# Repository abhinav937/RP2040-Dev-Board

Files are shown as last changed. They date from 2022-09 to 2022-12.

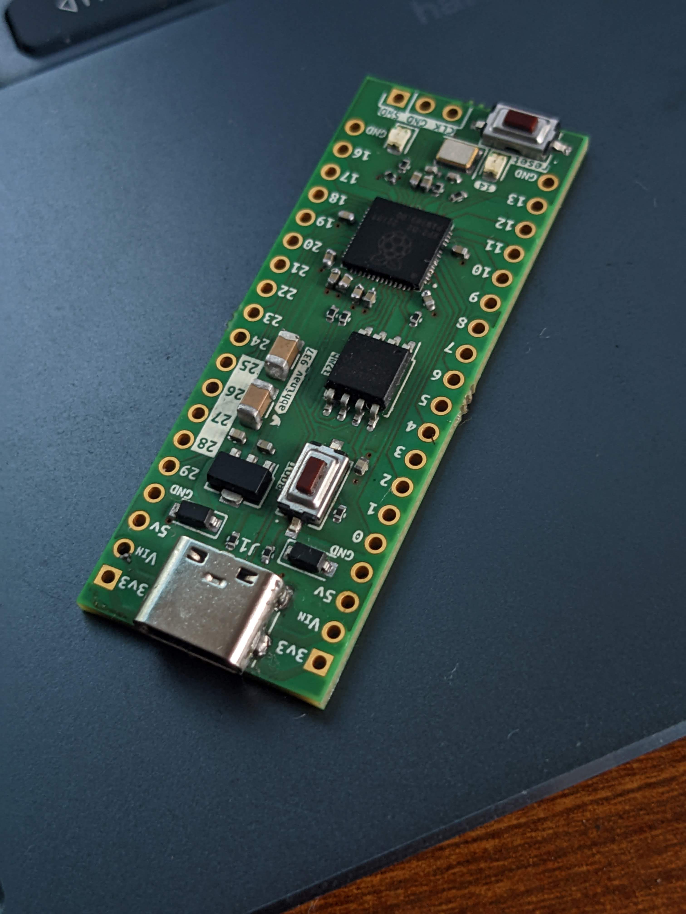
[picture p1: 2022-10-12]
Photos/PCBA/PXL_20220930_090836477.NIGHT.jpg

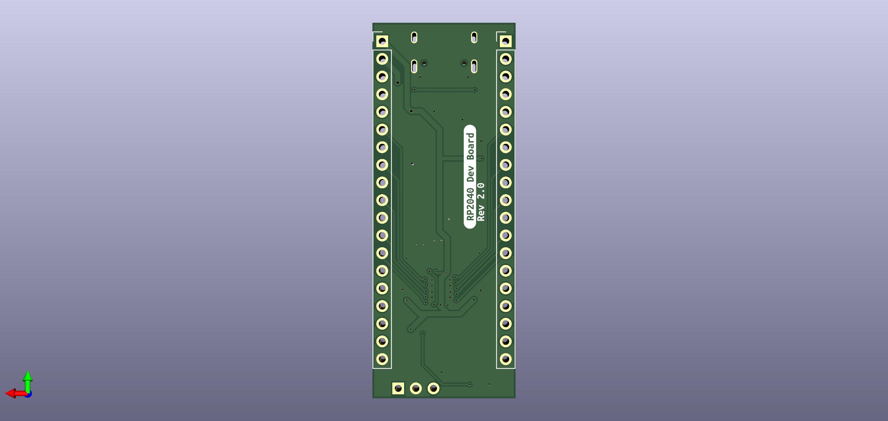
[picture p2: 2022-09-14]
Photos/Renders/pic_5.jpg

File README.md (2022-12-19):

# RP2040-Dev-Board
PCB Design(4 Layer) of Breadboard friendly RP2040 Dev Board with USB-C. <br /> 

#### Layer:

Layer 1: Front Cu <br /> 
Layer 2: Gnd <br /> 
Layer 3: Gnd <br /> 
Layer 4: Back Cu <br /> 

Initially my designs had inner layers as gnd and 3.3V, I got some netlist parity when I uploaded to my PCB manufacturer. But KiCad wasn't showing any errors in DRC, So I made both layers as Gnd.
#### Manufacturing
All components were purchased in [lcsc.com](lcsc.com) except RP2040, Which I purchased locally for 80Rs(~$1)/μC from robu.in. <br /> 

LCSC BOM: https://github.com/abhinav937/RP2040-Dev-Board/blob/main/RP2040_LCSC_BOM.csv <br /> 

I got my PCBs manufactured from [Aisler](aisler.net). <br /> 

Rev2 has lot of inspiration from michael rangen's PCB layout. Also I've used KiBuzzard for silkscreen texts, Which I personally like very much.
#### Refer my [documentation](https://github.com/abhinav937/RP2040-Dev-Board/blob/main/RP2040%20Dev%20Board%20Documentation_v01.pdf) for full information.

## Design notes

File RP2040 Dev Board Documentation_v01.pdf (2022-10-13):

# RP2040 Development Board

30 September 2022

Abhinav Chinnusamy

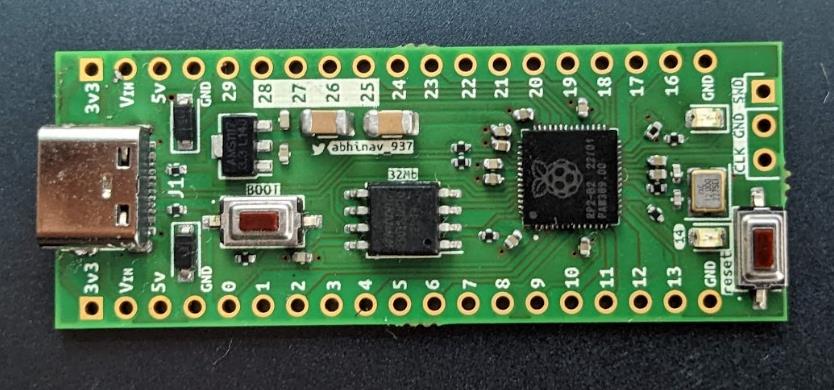
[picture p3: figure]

Figure 1. Top View of
assembled PCB

### Introduction

The RP2040 Development Board is a small, low-cost, versatile board. It has an RP2040 microcontroller, an onboard LED, a USB-C connector, and an SWD interface. The USB bootloader allows it to be flashed without any adapter in a drag-and-drop manner. It is also possible to flash and debug with its SWD interface using an external adapter.

### Hardware

- Dual-core Arm Cortex-M0+ processor running up to 133MHz
- 264KB on-chip SRAM
- 32MB onboard QSPI flash with XIP capabilities
- 26 GPIO pins
- 3 Analog inputs
- 2 UART peripherals
- 2 SPI controllers
- 2 I2C controllers
- 16 PWM channels
- USB 1.1 controller (host/device)
- 8 Programmable I/O (PIO) for custom peripherals
- On-board LED

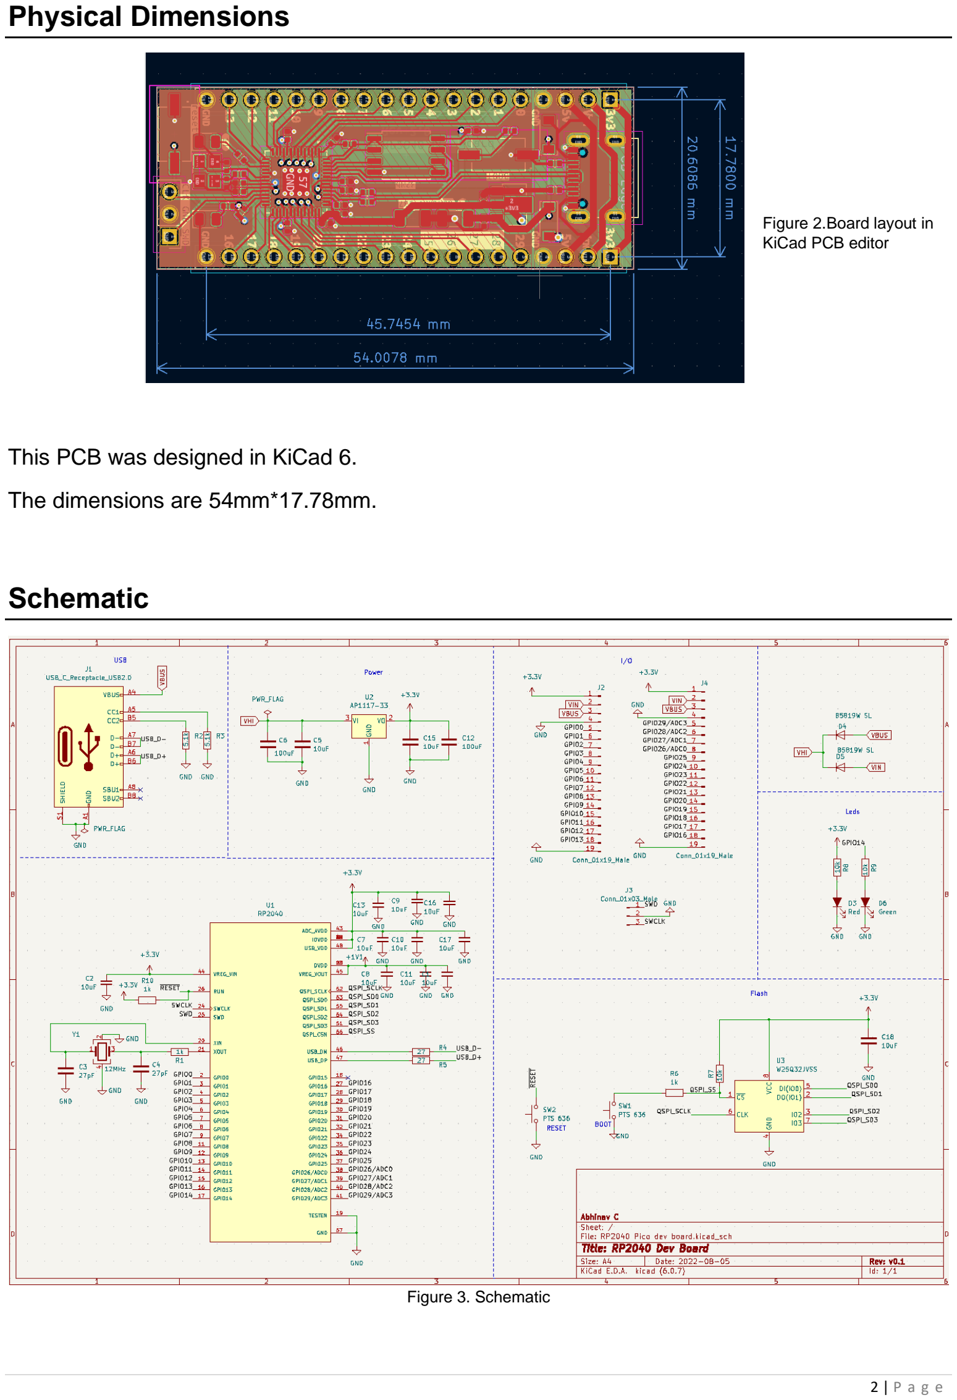
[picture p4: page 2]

2 | P a g e

### Physical Dimensions

Figure 2.Board layout in
KiCad PCB editor

This PCB was designed in KiCad 6.

The dimensions are 54mm*17.78mm.

### Schematic

Figure 3. Schematic

### Input supply

Figure 4. Power
and USB Section

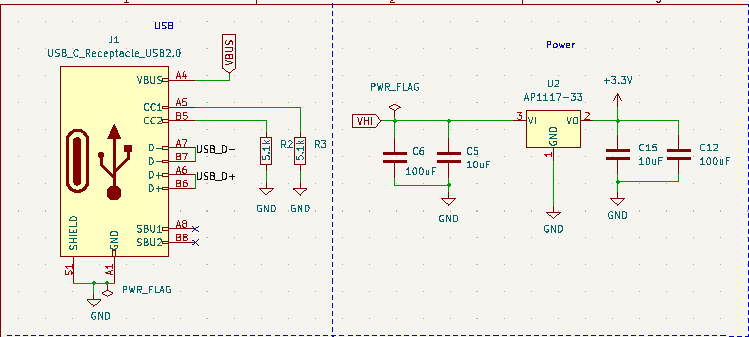
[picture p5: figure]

The input power connection for this Design is via the 5V VBUS of USB-C, as the CC pins are pulled down with 5.1k resistors. Also, it can be powered with the Vin pin up to 18V max and a min of 5V.

The Data lines in the USB-C port are connected to RP2040 directly, as it has native USB functionality.

We need only 3.3V for RP2040, so AMS1117 is chosen to deliver 3.3V up to 1A max.

It is advised to choose 0805 capacitors instead of smaller 0603 or 0402 because of DC Biasing.

Bigger the footprint, the lesser the DC Biasing (in MLCC, it also depends on brands). If the size is a constraint, more decoupling capacitors should be used.

### Crystal Oscillator

Figure 5. Oscillator

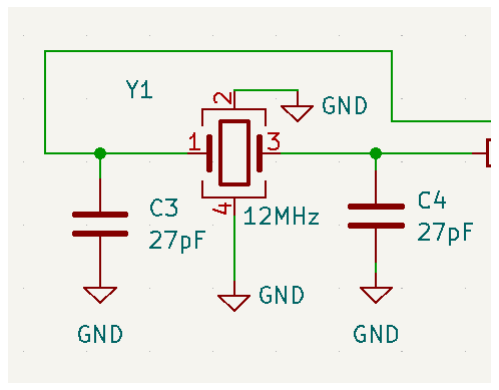
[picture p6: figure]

Do not forget to add load capacitance to the crystal. Otherwise, it might not oscillate.

Please choose the crystal's suitable capacitors to match its load capacitance. It's not a common value to use.

Refer to datasheets and calculate the C3 and C4(figure 5) for better results.

There are methods online to calculate it.

### How many decoupling capacitors are to be used?

Figure 6. A section of the schematic showing the RP2040 power supply inputs, voltage regulator, and decoupling capacitors

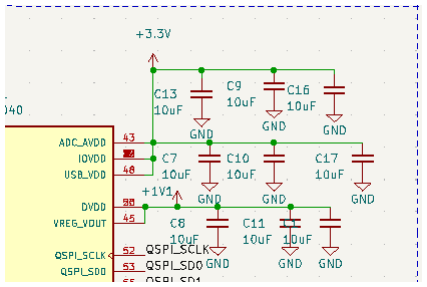
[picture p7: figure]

For the power input of RP2040, we require some decoupling capacitors for filtering purposes.

Raspberry Pi suggests using at least seven 100nF 0402 MLCC caps on 3.3V Power and two 100nF, 1uF 0402 MLCCs on 1.1V power pins.

If more oversized (>0402) caps are used, fewer capacitors can be placed because of lower DC bias in larger footprint caps.

These capacitors should be placed very close to the Microcontroller as possible, as it prevents the voltage level in the immediate vicinity from dropping too much when the current demand suddenly increases.

### LEDs

Figure 7. A section of the schematic showing the Onboard led and Power led.

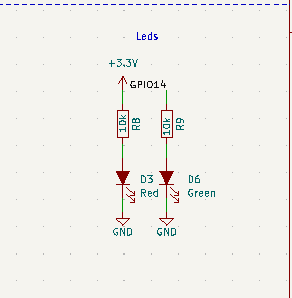
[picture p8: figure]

There are two LEDs on the PCB.

One (Red) is connected to the 3V power track.

Other LED(Green) connected to GPIO pin 14 for Onboard LED.

## PCB Design

The PCB was designed in KiCad v6 with 4 layers, the middle layers being gnd and the outer layers being mixed signal and Power.

### Physical Stackup

Figure 8.
Stack-up
specifications
of the Board.

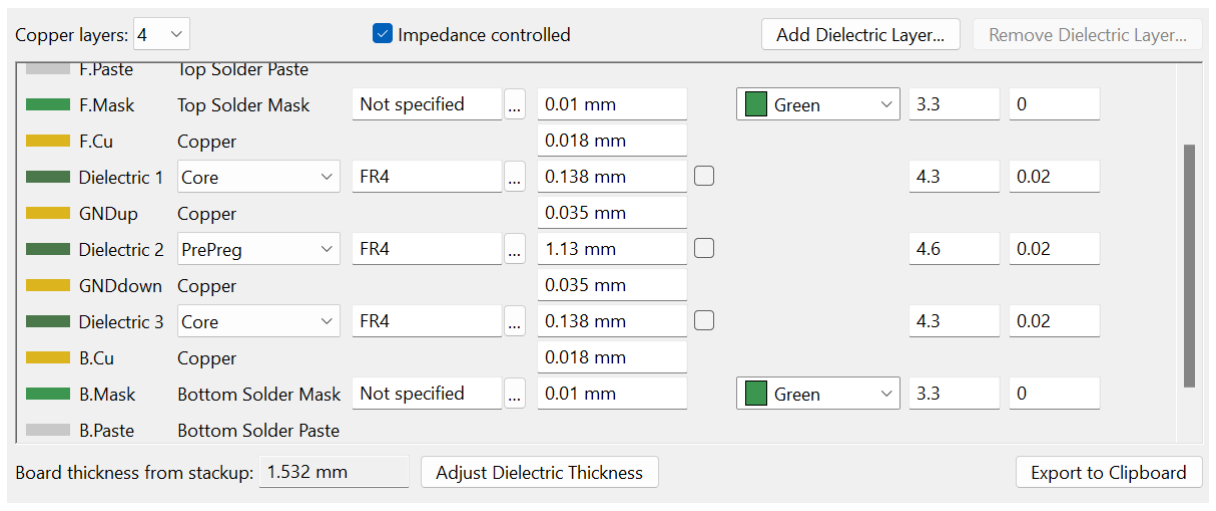
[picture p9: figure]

The above figure shows the stack-up specifications of the Board. This depends on the manufacturing capability of the PCB Manufacturer. I used the specs listed by AISLER for 4-layer Board.

### Tracks and Vias

Figure 9. Pre-defined Track and Via dimensions.

I've used 3 different widths for tracks—the lesser width track(0.2mm) for connecting microcontroller pins to other components. And the broader track for Power.

Track width depends on the current it can handle under a specific temperature rise. KiCad has an inbuilt tool to calculate it.

One way to have narrow tracks is to increase the thickness of the copper layer. I used 1oz of copper thickness.

Increasing the thickness increases the manufacturing cost of PCBs.

### Vias in uC's Copper Pad

Figure 10. A section of the PCB Design showing vias placed in RP2040 footprint.

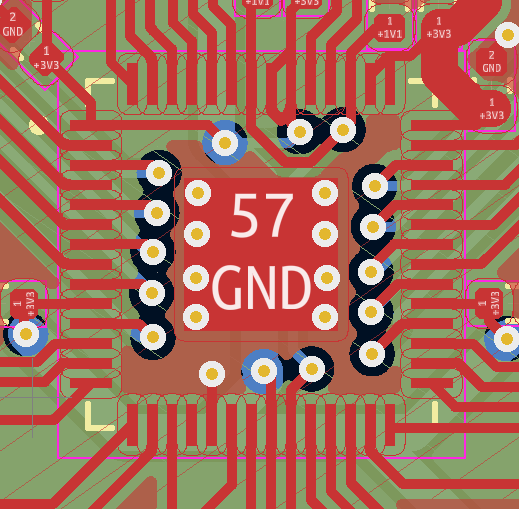
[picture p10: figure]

The unconnected vias on copper pads were placed for heat dissipation for the Microcontroller.

### Copper fills

Figure 11. A section of the PCB Design showing the copper fill zone (highlighted).

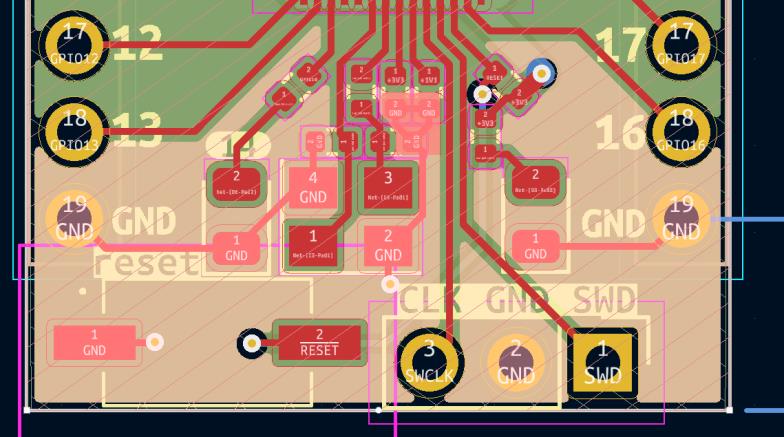
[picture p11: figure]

Copper fill zones are placed in PCBs to increase EMI performance and heat dissipation, and signals can take the shortest path.

In this Design, I've placed copper fills in both inner layers, which are grounded. And there are a few copper fills on the top and bottom for Power and Gnd.

### Breadboard Friendly?

Figure 12. A section of the PCB Design showing distance between header pins pads.

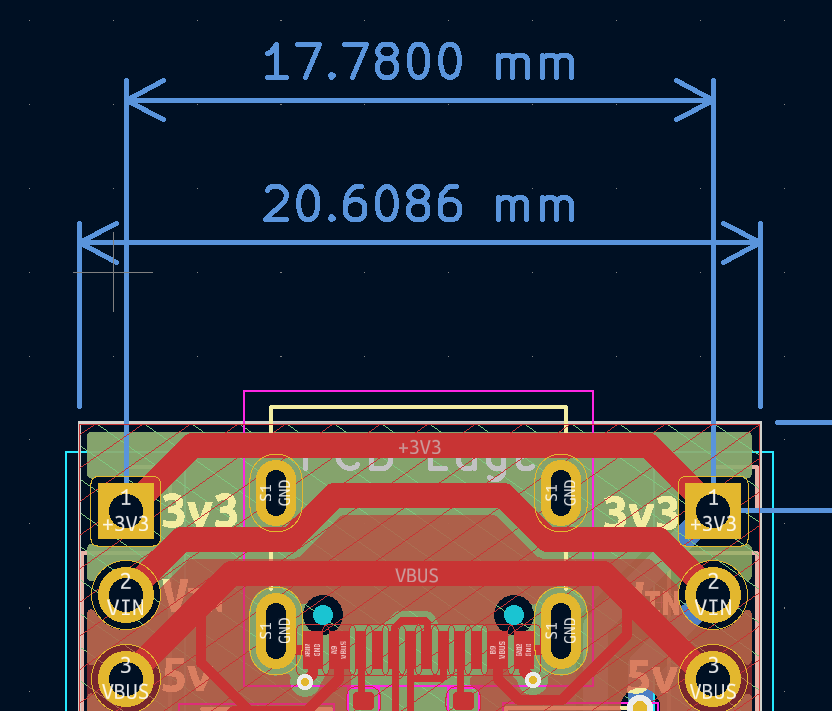
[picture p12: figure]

This Board was made with consideration to be breadboard friendly. So, the header pins are separated at 17.78mm, like Arduino Nano.

### Silkscreen Text

Figure 13. KiBuzzard tool for silkscreen text.

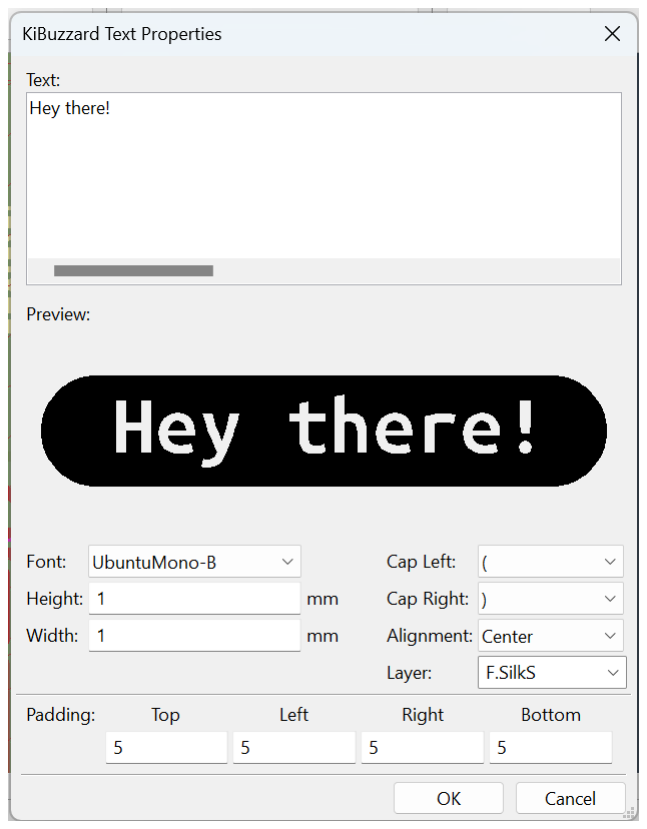
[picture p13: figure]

KiBuzzard is a KiCad Plugin for creating labels in various fonts and inverted backgrounds developed by gregdavill. (https://github.com/gregdavill/KiBuzzard)

This plugin allows the creation of boxed texts in various formats in silkscreen. I recommend this plugin very much.

### PCB Manufacturing

To manufacture the designed PCB, export the Gerber and drill files and upload them to the PCB manufacturer's website.

Or there are plugins for top-rated PCB manufacturers like AISLER, PCBWay, JLCPCB, et Cetra.

After installing the plugin, A single click to upload required files directly to their website.

Figure 14. AISLER push plugin in KiCad.

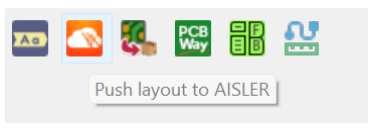
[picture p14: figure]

It's preferred to order a stencil with the PCBs if assembly service is not chosen. There are 0402 components, and the Microcontroller lead pitch (pin to pin) is 0.4mm.

Personal preference:

I prefer AISLER for manufacturing the PCBs. There are no delivery charges for basic delivery service; they were delivered to India within 7 days after the order was dispatched, and no customs duties were levied.

### Manufactured PCB from AISLER

Figure 15.
Manufactured
PCB.

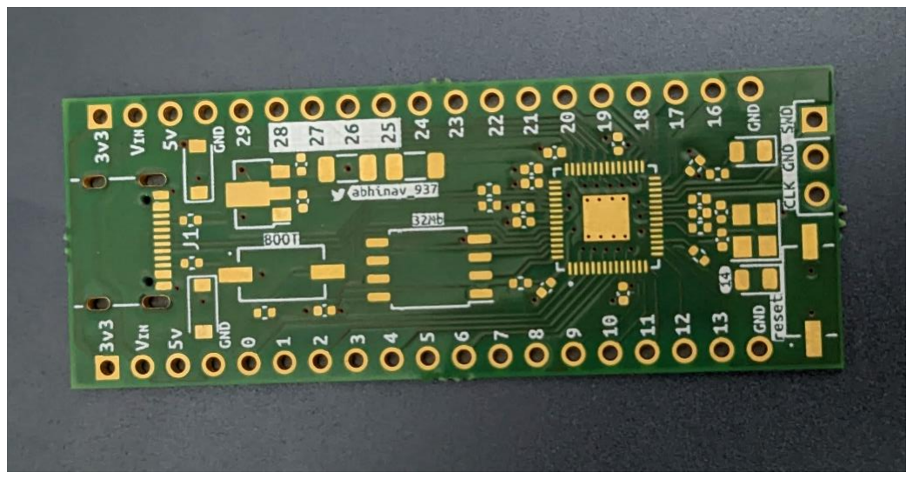
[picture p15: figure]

### Component sourcing

I sourced all components from lcsc.com except RP2040. RP2040 was purchased from robu.in.

There were no custom duties levied on components. But it took around 15 days for delivery—longer queue times in customs clearance.

Purchase more components than what you require for assembly.

I lost many SMD components while placing them on Board.

### Assembly

After sourcing all components and PCBs, tools like a Reflow oven or Hot Plate, Solder paste, Flux, and soldering iron are required.

I reflowed the components with a Reflow Oven (Model: T962A).

Figure 16. T962A Reflow oven

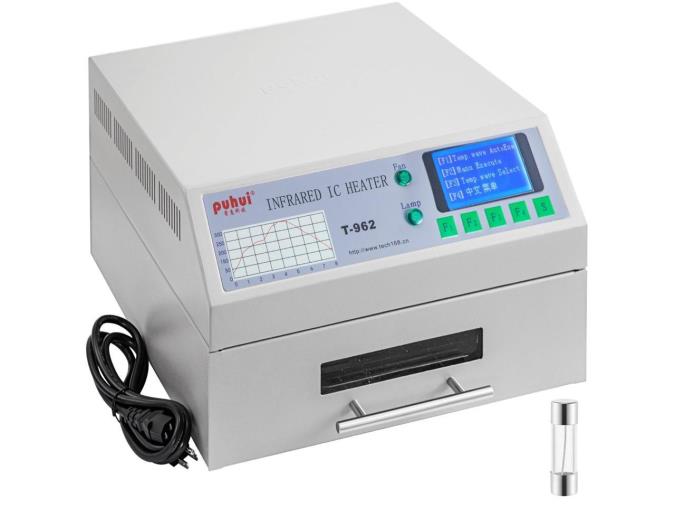
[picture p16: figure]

Assembly process:

1. Solder Paste deposition
2. Parts placement
3. Reflowing the PCB
4. Rework on bridged pads

### Solder Paste deposition

To apply solder paste on the pads, Secure the PCBs on a flat surface with pre-cut holders. If you don't have one, you may use some trash PCBs of the same thickness to hold it.

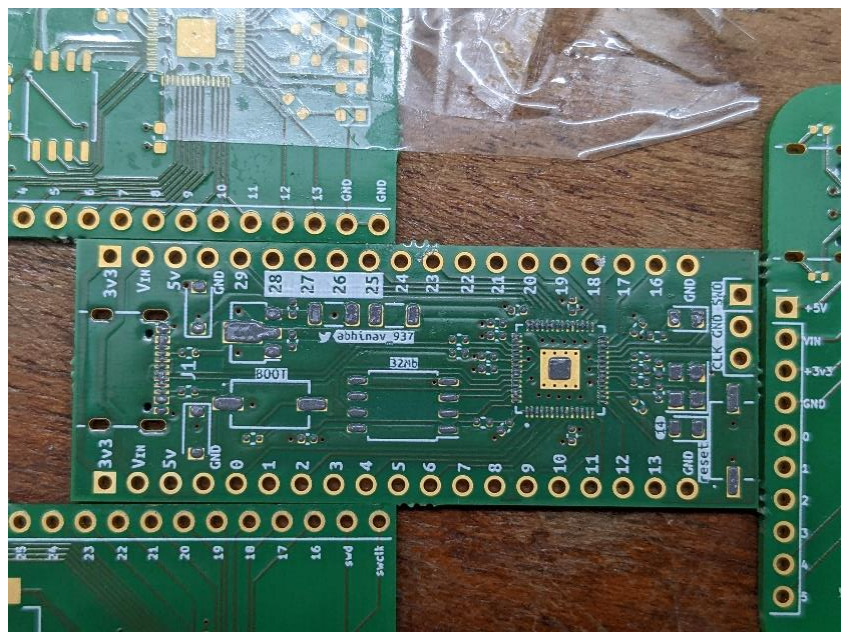
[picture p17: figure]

Figure 17. Securing the
PCB with trash PCBs on a
flat surface.

Then align the stencil on the top of the PCB, ensure it's properly aligned, and secure it for best results.

Figure 18. Aligning the
PCB and securing it.

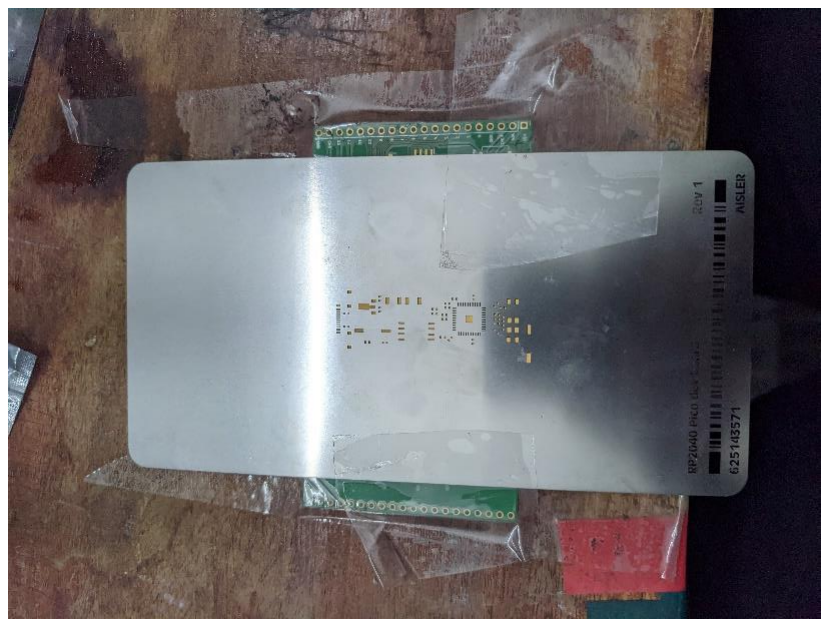
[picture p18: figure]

Prepare the solder paste by mixing it properly. Make sure to check that it's not expired.

Refrigerated solder paste gives the best results.

Take some amount(excess) solder paste and place it on one side of the stencil.

Using a squeegee or an old credit card, slide the solder paste on the stencil at an angle of 60˚.

Then gently remove the stencil.

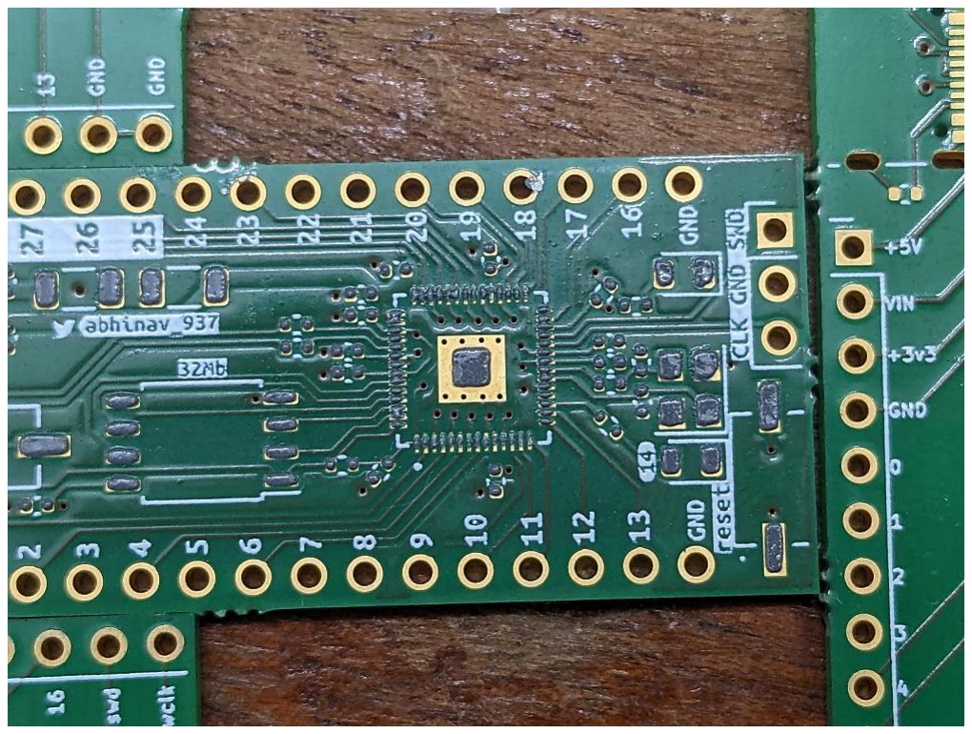
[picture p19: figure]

Figure 19. Solder
paste applied
PCB.

### Parts placement

Before placing the parts, have a copy of BOM to mark the components placed and sourced to avoid confusion during placement.

I prefer iBOM, a KiCad plugin, and a convenient BOM listing that can correlate visually and easily search for components and their placements on the PCB.

Figure
20.
iBOM
tool.

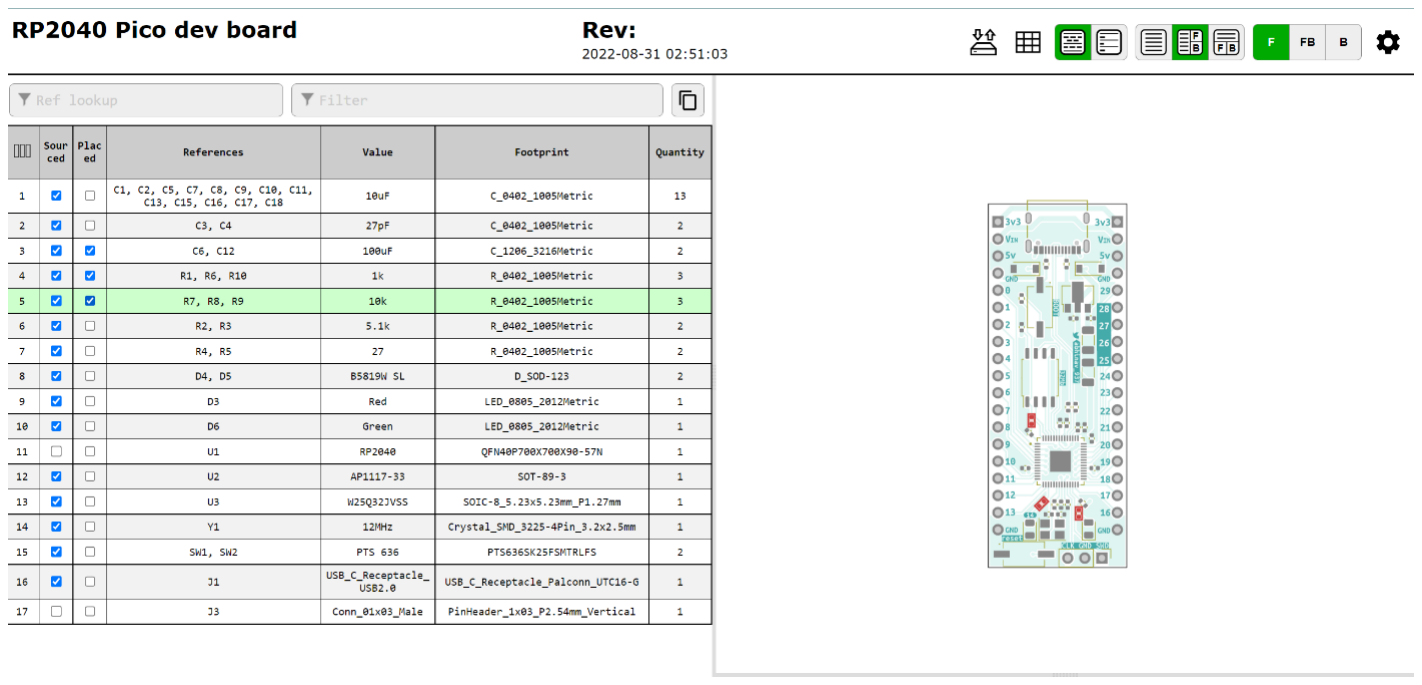
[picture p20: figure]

To place the SMD components, use a bent-tip tweezer to pick and place it on PCB and give a gentle push from the top.

Try to place the components properly on the first try. Re-positioning may push the solder paste and disturb it.

Do not place THT components for reflow. It can be hand soldered later.

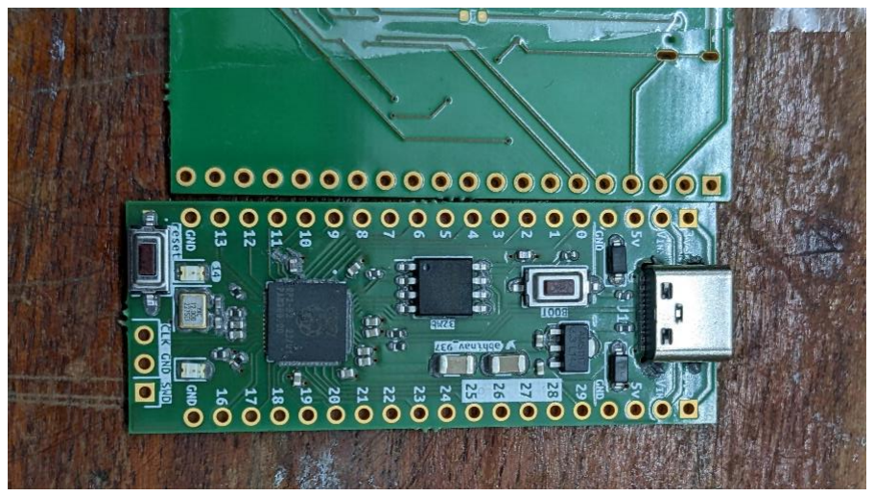
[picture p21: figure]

Figure 21. PCB after
placing the
components and ready
for reflowing.

### Reflowing the PCB

The first step in reflowing is to set the temperature profile in the reflow oven.

T962A reflow oven has 8 different temperature profiles. You can choose one after referring to your solder paste datasheet and components datasheets.

I used a custom profile which gave a better result for the XG-50 solder paste.

Figure 22. Custom
reflow profile on T962A
Oven.

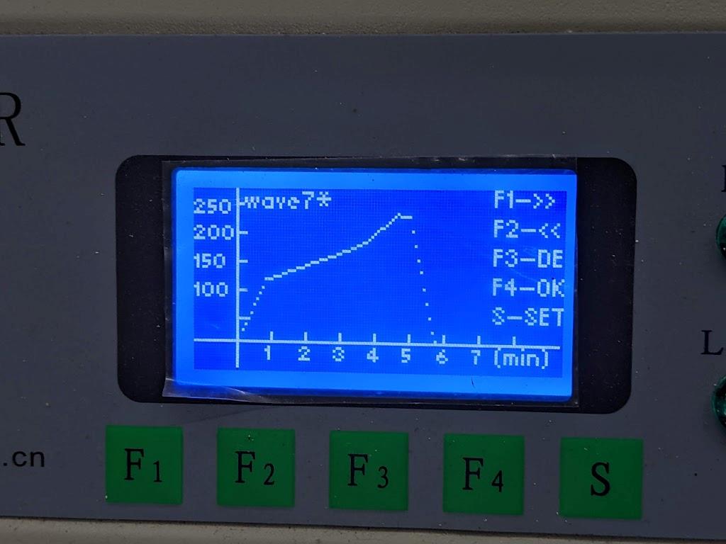
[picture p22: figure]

Now, gently place the PCB in the Oven and start the reflow oven.

Using this Oven in a ventilated room or with a venting system to extract the fumes is good practice.

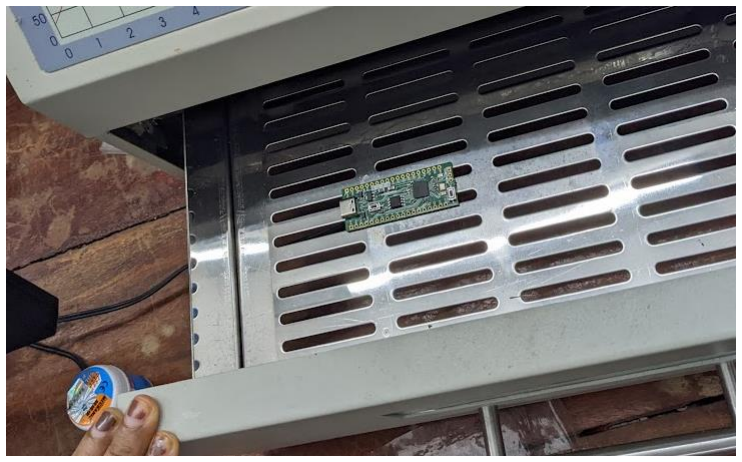
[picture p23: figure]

Figure 23.
Semi-assembled
PCB placed
in Oven for
reflowing.

It takes 5 minutes and 20 seconds to complete the reflow for this solder profile. When the Oven starts beeping, please turn it off and wait some time for cooldown as the inside temperature could be more than 100˚.

Please do not take the Board right after the reflow process ends; the components are loose in hot solder.

After the Board cools down, take it out and check for solder bridges and short circuits.

### Rework on the bridged pads

It's not always that we get a perfect reflow.

Due to excess solder paste on some pads, the neighbouring pads get bridged.

The uC in my PCB got bridged pins.

So, we can rework it using one of the following methods.

### 1. Hot air rework station

We can reflow the component using the hot air station and scrap the excess solder.

Use Kapton tape to cover the other components while reworking on the uC.

Figure 24. Assembled
PCB Kapton taped for
rework on the uC.

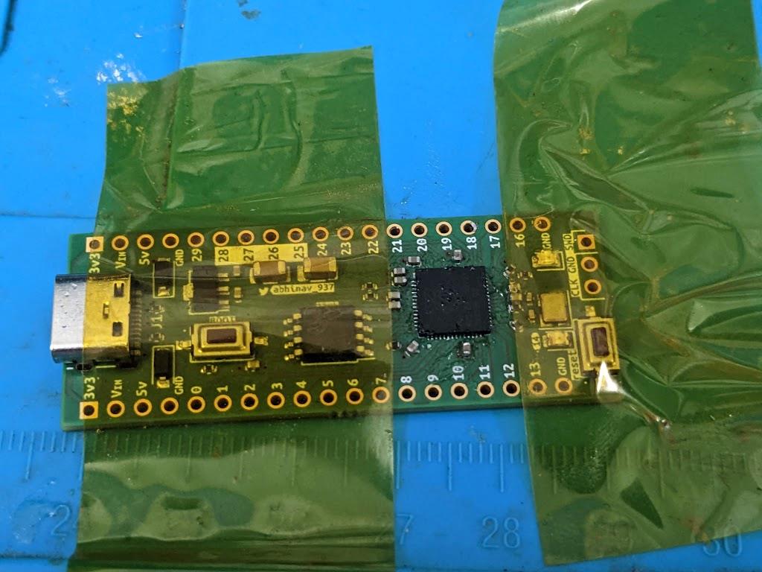
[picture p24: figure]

This method was not successful for me in getting rid of bridged pads.

### 2. Using a soldering iron

My idea was to try using a sharp tip soldering iron to remove the bridges, but I was unsuccessful.

Next, I tried using a properly tinned, angled flat tip soldering iron and successfully removed the bridges.

But still, there were shorts in the Power and GPIO pins of uC.

Finally, I came to know that uC was bridged from the inside due to excess solder paste on the pads.

So, I tried another method to resolve it.

### 3. Reflowing once again in Oven

I removed the uC from the PCB using the Hot air station and cleaned the pads and added some solder to it.

Then I applied some flux to the PCB, placed the uC, and reflowed in Oven.

Now there are no bridged pads, and connectivity is fine.

Still, the pads and vertical side of uC were not soldered properly. So, I reworked it with a soldering iron.

NOTE:

Use an ample amount of Flux while doing any rework.

Reflowing the PCBA multiple times can change the properties of the components.

E.g., Reflowing the crystal oscillator more than once can change its frequency.

After resolving all the issues and checking the connectivity of pads and power tracks, we can solder the THT components and Power up the Board.

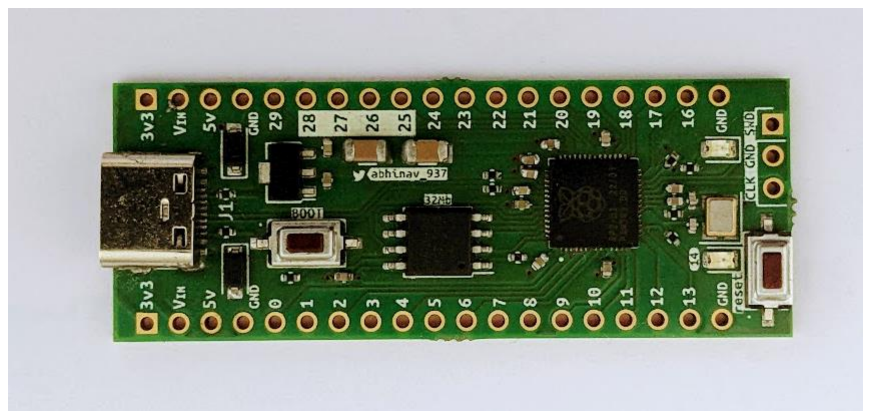
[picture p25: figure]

Figure 25. Fully
assembled working PCB
of RP2040 dev board.

### Testing

Ensure the Board has no shorts, and connect a USB-C cable from a charging brick or a computer.

If the Onboard Power led lights up, then Board is working fine (At least in the power section).

Connect the Board to a computer while pressing the Boot button and release it when mass storage (RPI-RP2) is detected.

This ensures that Board is working with full functionality.

If mass storage is not detected, solder the Flash pins of uC to pads properly or check for bridging.

NOTE: No drivers are required for USB serial connection.

Once Everything is working correctly, we can drop the compiled .UF2 file on the mass storage, and it starts running the program.

RP2040 officially supports C/C++ and MicroPython.

For MicroPython, Thonny (https://thonny.org/) IDE allows you to code in MicroPython, compile, and run on the Board by selecting the proper interpreter and flashing a special firmware.

For C/C++, VS Code and a few extensions allow us to write and compile the program with debugging functionalities.

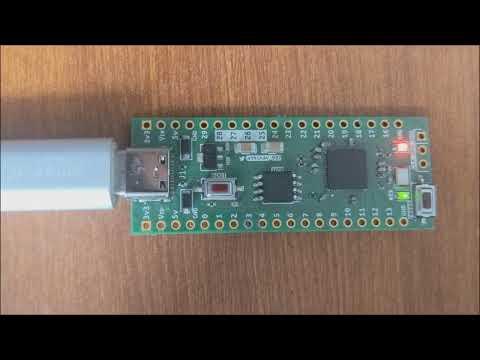
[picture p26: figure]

On-board Led Blink test

### References

https://datasheets.raspberrypi.com/rp2040/hardware-design-with-rp2040.pdf

https://twitter.com/sad_electronics

https://www.youtube.com/watch?v=kcwvuwetgEQ

https://www.digikey.in/en/maker/projects/hardware-design-with-the-rp2040-part-1-schematic/c4326f0fd813413698d617cf625125ee (https://www.digikey.in/en/maker/projects/hardware-design-with-the-rp2040-part-1-schematic/c4326f0fd813413698d617cf625125ee)

https://github.com/mrangen/RP2040-Dev-Board

https://github.com/gregdavill/KiBuzzard

https://www.kicad.org/

https://aisler.net/

https://lcsc.com/

https://www.puhuit.com/main/page_products_t962a_ir_ovenic_heater.html

https://thonny.org/

A Special thanks to sad_electronics (https://twitter.com/sad_electronics) and peg_iitdh (https://twitter.com/peg_iitdh) for their continuous support.

Design files: https://github.com/abhinav937/RP2040-Dev-Board

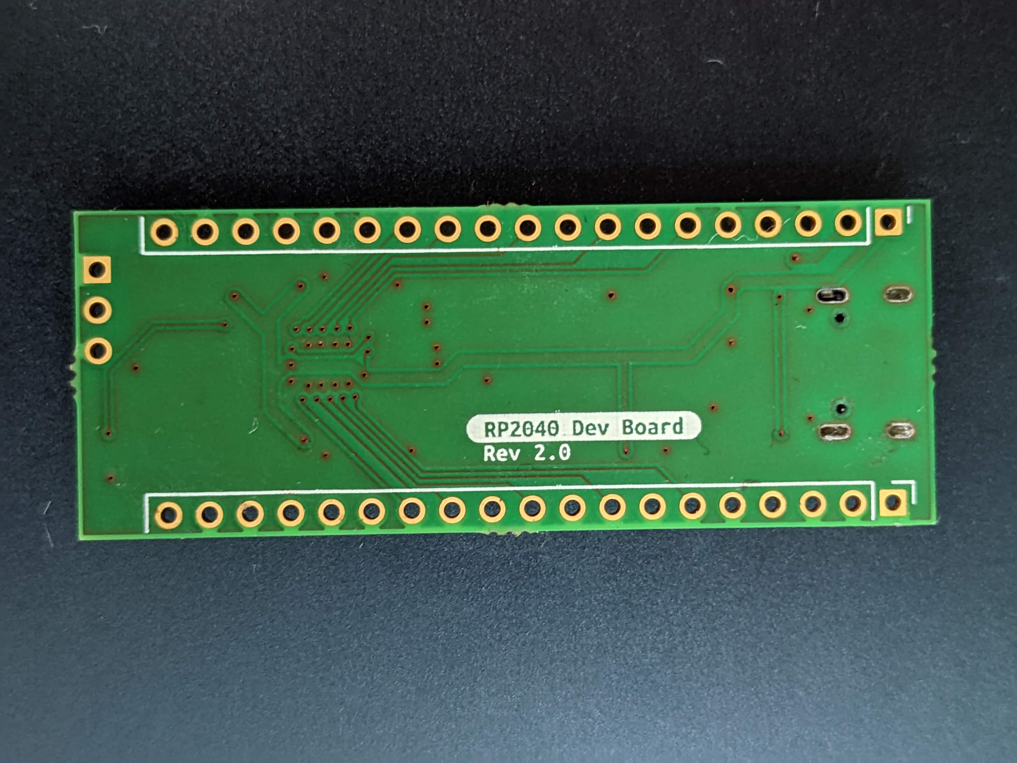
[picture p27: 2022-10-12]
Photos/PCBA/PXL_20220930_091015371.NIGHT.jpg

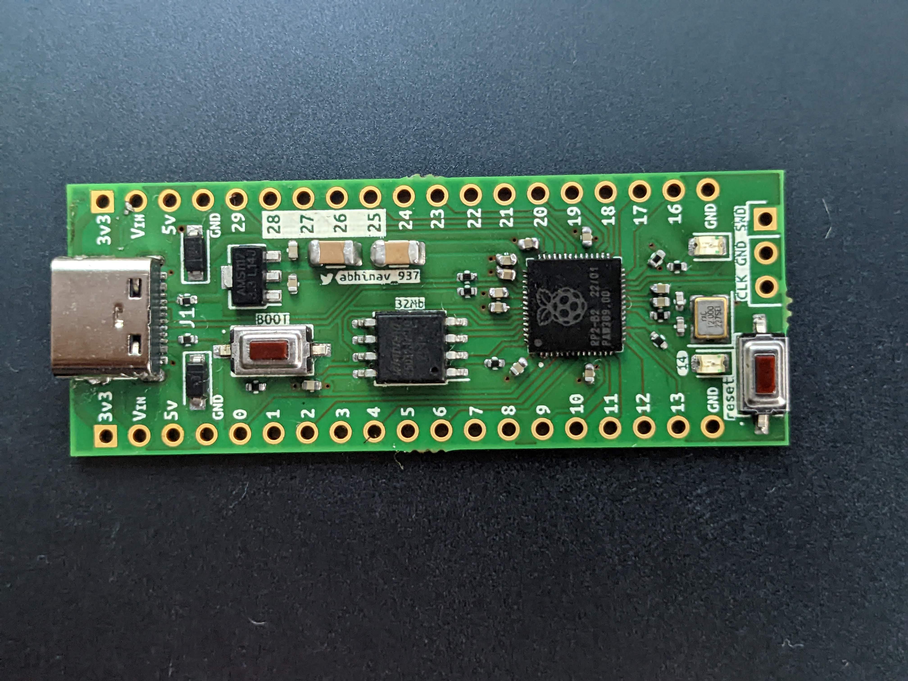
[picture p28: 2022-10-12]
Photos/PCBA/PXL_20220930_090942642.NIGHT.jpg

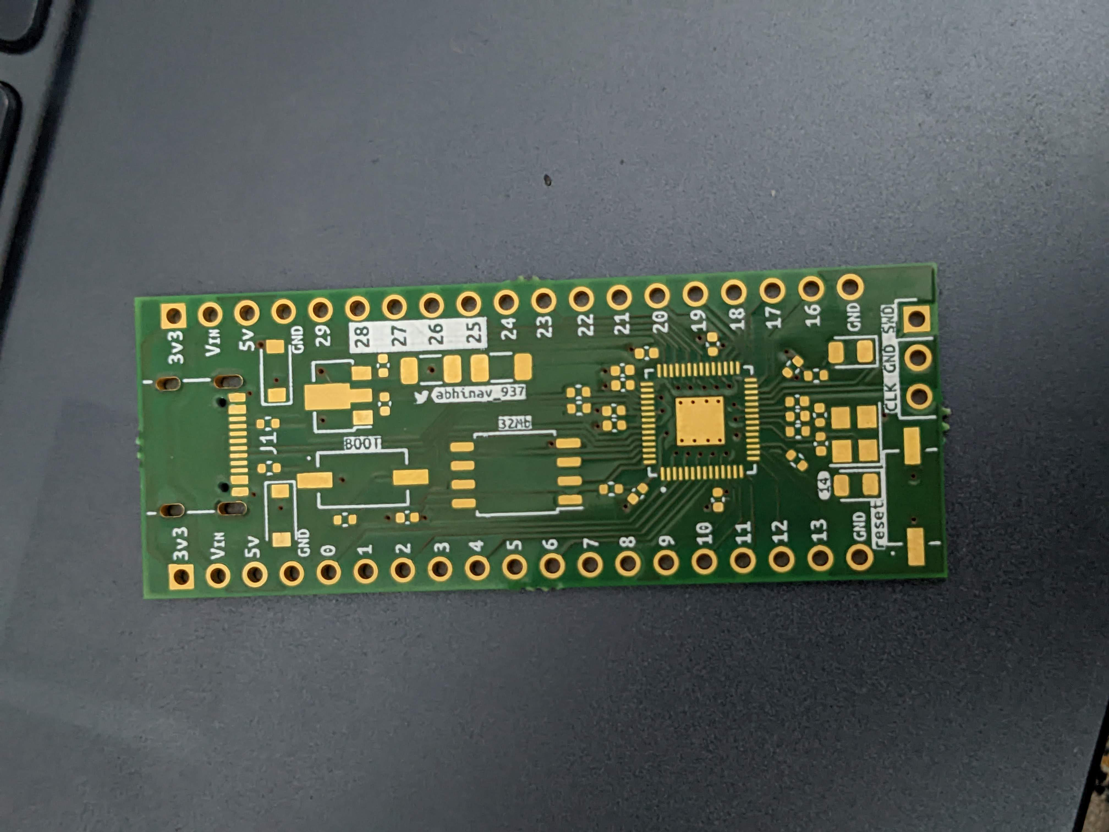
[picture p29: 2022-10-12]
Photos/PCBA/PXL_20220921_171338347.NIGHT.jpg

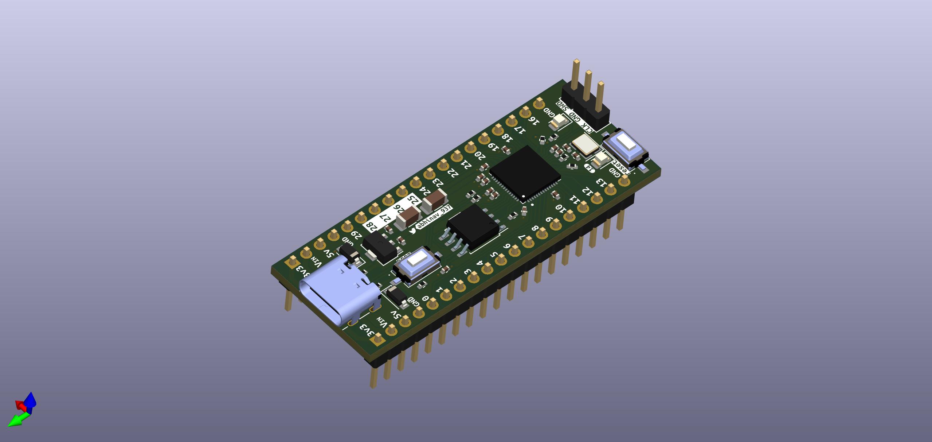
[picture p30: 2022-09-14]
Photos/Renders/pic_3.jpg

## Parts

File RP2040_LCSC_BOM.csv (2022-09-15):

LCSC Part Number | Manufacture Part Number | Manufacturer | Customer NO. | Package | Description | RoHS | Order Qty. | Min\Mult Order Qty. | Unit Price | Order Price
C8598 | B5819W SL | Jiangsu Changjing Electronics Technology Co., Ltd. |  | SOD-123 | 40V 600mV@1A 1A SOD-123 Schottky Barrier Diodes (SBD) ROHS | YES | 20 | 20\20 | $0.033900 | $0.68
C2689642 | PTS636SK25SMTRLFS | C&K |  | - | - Tactile Switches ROHS | YES | 12 | 1\1 | $0.097000 | $1.16
C15525 | CL05A106MQ5NUNC | Samsung Electro-Mechanics |  | 0402 | 6.3V 10uF X5R ±20% 0402 Multilayer Ceramic Capacitors MLCC - SMD/SMT ROHS | YES | 100 | 50\50 | $0.003300 | $0.33
C15008 | CL31A107MQHNNNE | Samsung Electro-Mechanics |  | 1206 | 6.3V 100uF X5R ±20% 1206 Multilayer Ceramic Capacitors MLCC - SMD/SMT ROHS | YES | 15 | 5\5 | $0.078400 | $1.18
C1570 | 0402CG300J500NT | FH (Guangdong Fenghua Advanced Tech) |  | 0402 | 50V 30pF C0G ±5% 0402 Multilayer Ceramic Capacitors MLCC - SMD/SMT ROHS | YES | 100 | 100\100 | $0.001100 | $0.11
C11702 | 0402WGF1001TCE | UNI-ROYAL(Uniroyal Elec) |  | 0402 | 62.5mW Thick Film Resistors 50V ±100ppm/℃ ±1% -55℃~+155℃ 1kΩ 0402 Chip Resistor - Surface Mount ROHS | YES | 100 | 100\100 | $0.000600 | $0.06
C25744 | 0402WGF1002TCE | UNI-ROYAL(Uniroyal Elec) |  | 0402 | 62.5mW Thick Film Resistors 50V ±100ppm/℃ ±1% -55℃~+155℃ 10kΩ 0402 Chip Resistor - Surface Mount ROHS | YES | 100 | 100\100 | $0.000700 | $0.07
C25905 | 0402WGF5101TCE | UNI-ROYAL(Uniroyal Elec) |  | 0402 | 62.5mW Thick Film Resistors 50V ±100ppm/℃ ±1% -55℃~+155℃ 5.1kΩ 0402 Chip Resistor - Surface Mount ROHS | YES | 100 | 100\100 | $0.000600 | $0.06
C84256 | NCD0805R1 | Foshan NationStar Optoelectronics |  | 0805 | Red 0805 Light Emitting Diodes (LED) ROHS | YES | 50 | 50\50 | $0.013000 | $0.65
C84257 | NCD0805C1 | Foshan NationStar Optoelectronics |  | 0805 | Green/Yellow-Green 0805 Light Emitting Diodes (LED) ROHS | YES | 50 | 50\50 | $0.016800 | $0.84
C165948 | TYPE-C-31-M-12 | Korean Hroparts Elec |  | SMD | 250mA 1 16 Female Type-C SMD USB Connectors ROHS | YES | 15 | 1\1 | $0.219300 | $3.29
C179173 | W25Q32JVSSIQ | Winbond Elec |  | SOIC-8 | SOIC-8 NOR FLASH ROHS | YES | 10 | 1\1 | $0.439300 | $4.39
C9002 | X322512MSB4SI | Yangxing Tech |  | SMD3225-4P | 12MHz SMD Crystal Resonator 20pF ±10ppm ±30ppm -40℃~+85℃ SMD3225-4P Crystals ROHS | YES | 10 | 5\5 | $0.090200 | $0.90
C5120796 | AMS1117-3.3V | MSKSEMI |  | SOT-89 | SOT-89 Linear Voltage Regulators (LDO) ROHS | YES | 20 | 10\10 | $0.074200 | $1.48
C25100 | 0402WGF270JTCE | UNI-ROYAL(Uniroyal Elec) |  | 0402 | 62.5mW Thick Film Resistors 50V ±100ppm/℃ ±1% -55℃~+155℃ 27Ω 0402 Chip Resistor - Surface Mount ROHS | YES | 100 | 100\100 | $0.000500 | $0.05

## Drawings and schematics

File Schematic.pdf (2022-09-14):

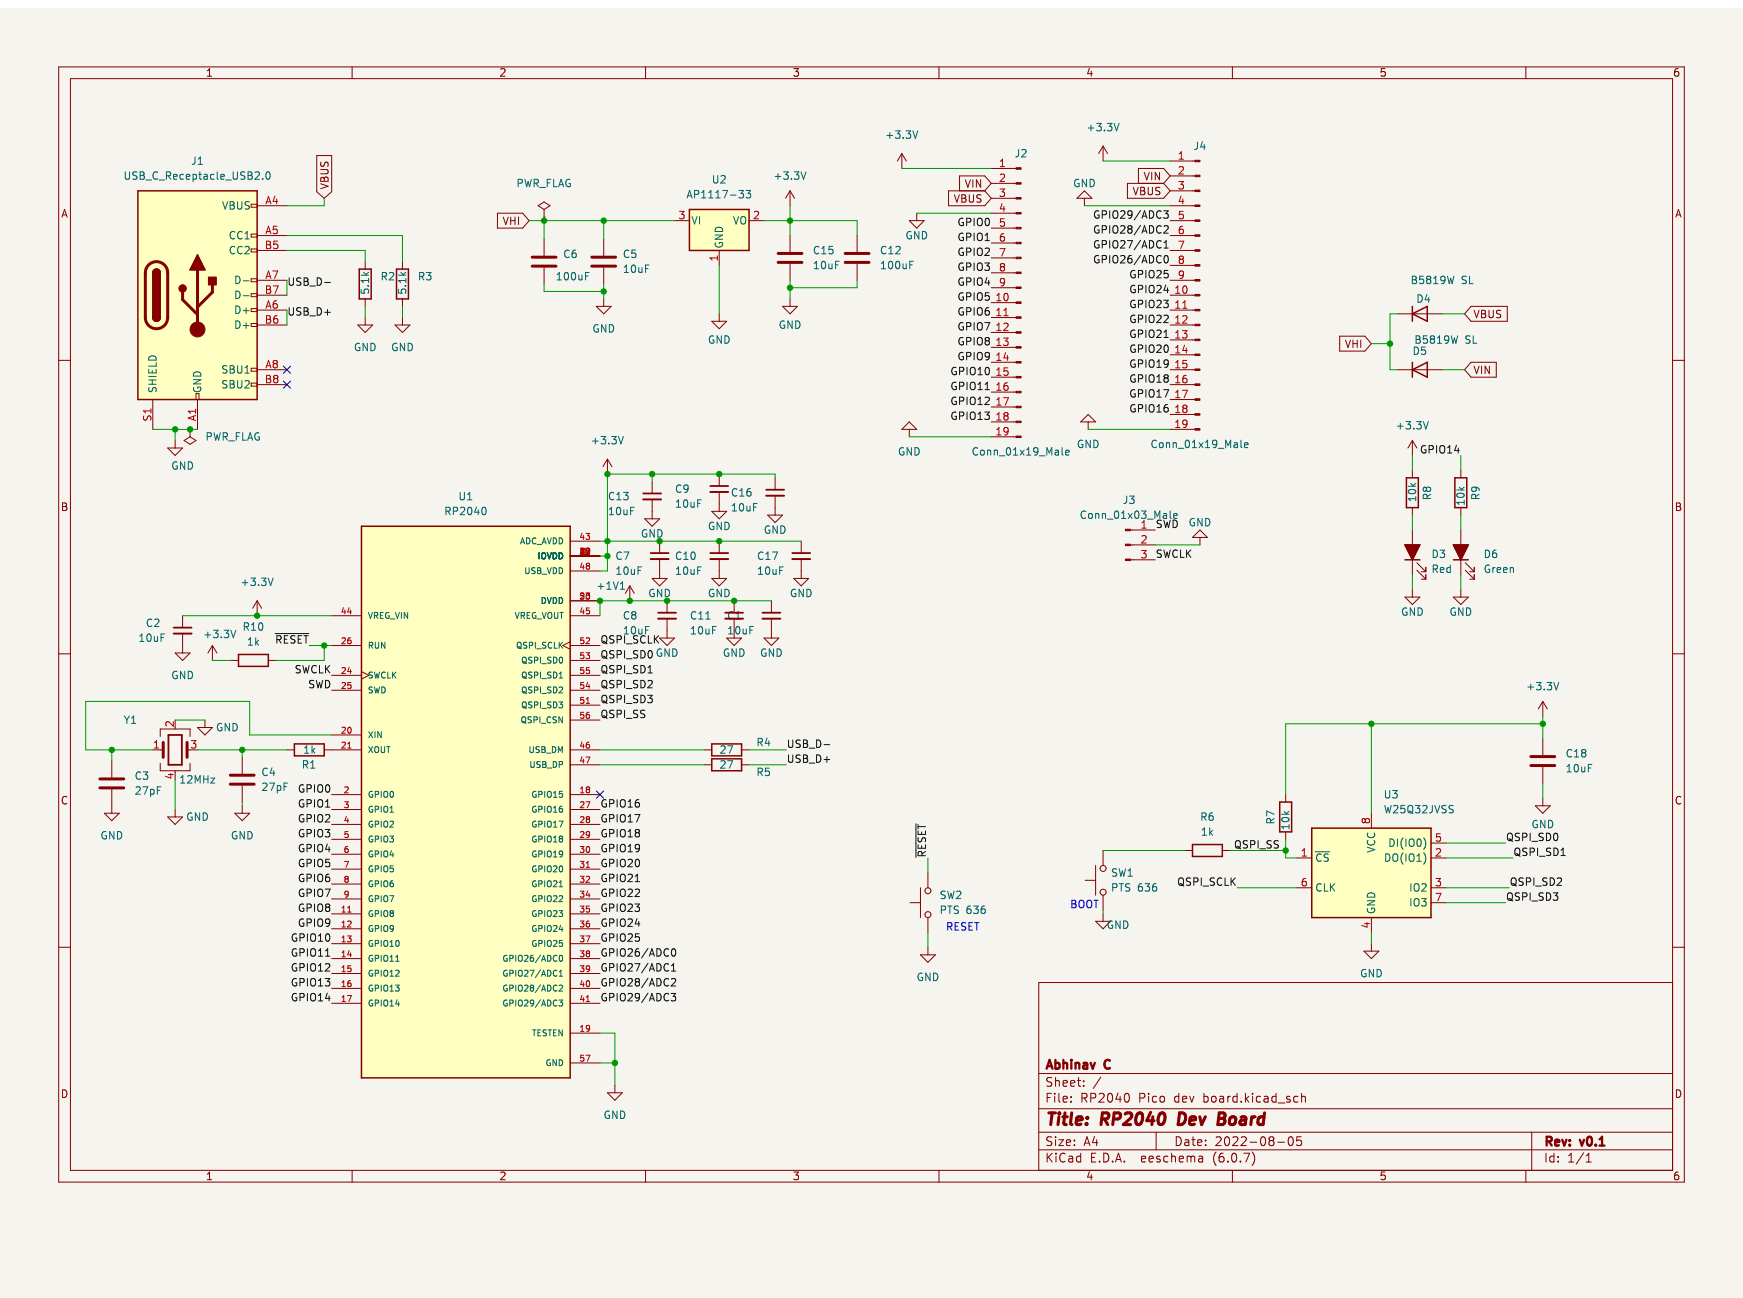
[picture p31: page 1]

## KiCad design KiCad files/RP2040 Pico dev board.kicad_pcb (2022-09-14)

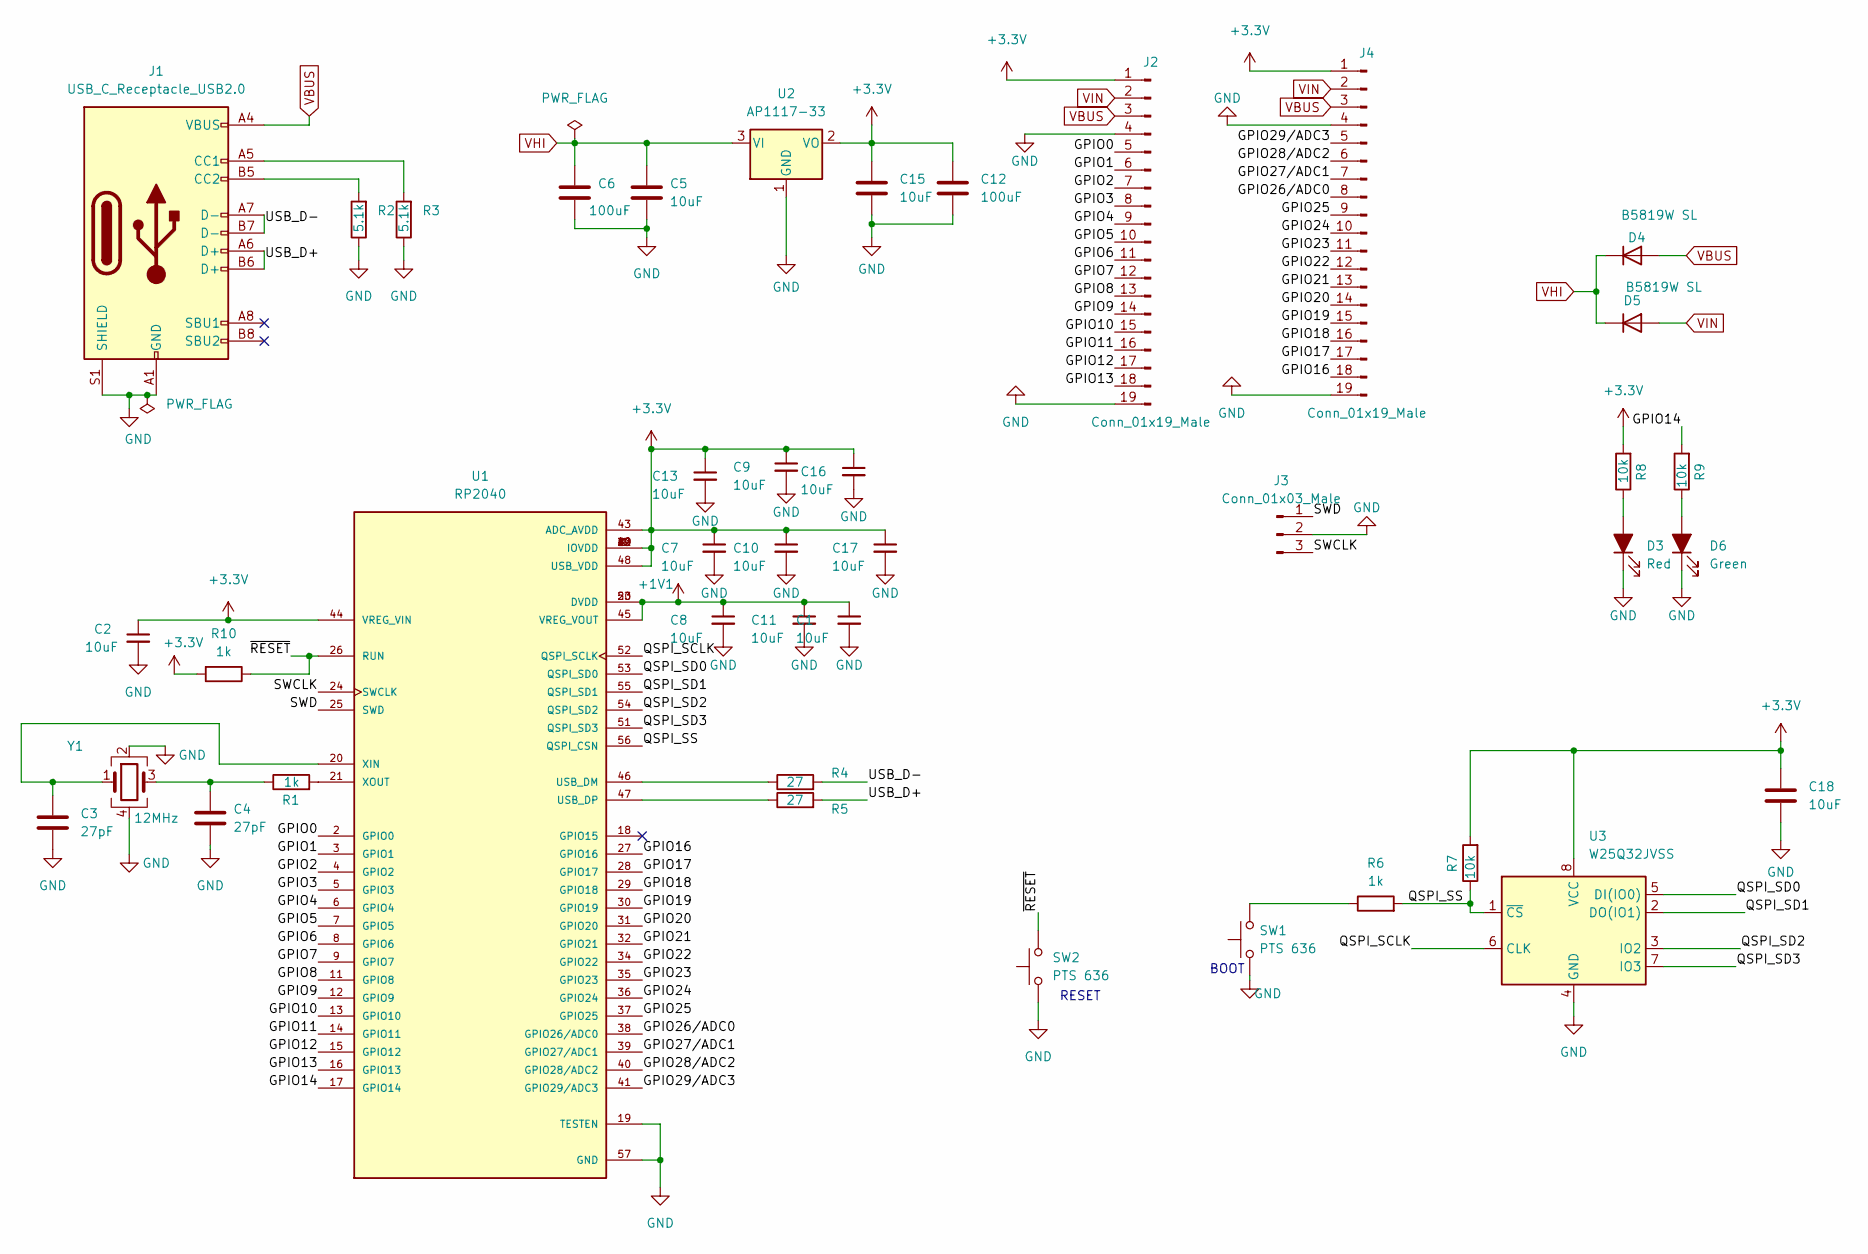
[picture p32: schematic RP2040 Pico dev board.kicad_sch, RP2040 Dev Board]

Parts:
C1, C2, C7, C8, C9, C10, C11, C13, C16, C17: 10uF; C_0402_1005Metric; JLCPCB P/N C15525
C3, C4: 27pF; C_0402_1005Metric
C5, C15, C18: 10uF; C_0402_1005Metric
C6, C12: 100uF; C_1206_3216Metric
D3: Red; LED_0805_2012Metric; JLCPCB P/N C2297
D4, D5: B5819W SL; D_SOD-123
D6: Green; LED_0805_2012Metric; JLCPCB P/N C2297
J1: USB_C_Receptacle_USB2.0; USB_C_Receptacle_Palconn_UTC16-G
J2, J4: Conn_01x19_Male; PinHeader_1x19_P2.54mm_Vertical
J3: Conn_01x03_Male; PinHeader_1x03_P2.54mm_Vertical
R1: 1k; R_0402_1005Metric; JLCPCB P/N C11702
R2, R3: 5.1k; R_0402_1005Metric
R4, R5: 27; R_0402_1005Metric; JLCPCB P/N C25100
R6, R10: 1k; R_0402_1005Metric
R7, R8, R9: 10k; R_0402_1005Metric; JLCPCB P/N C25744
SW1, SW2: PTS 636; PTS636SK25FSMTRLFS
U1: RP2040; QFN40P700X700X90-57N; PARTREV 1.6.1
U2: AP1117-33; SOT-89-3
U3: W25Q32JVSS; SOIC-8_5.23x5.23mm_P1.27mm
Y1: 12MHz; Crystal_SMD_3225-4Pin_3.2x2.5mm; JLCPCB P/N C9002

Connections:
+1V1: C1.1, C8.1, C11.1, U1.23 (DVDD), U1.45 (VREG_VOUT), U1.50 (DVDD)
+3V3: C2.1, C7.1, C9.1, C10.1, C12.1, C13.1, C15.1, C16.1, C17.1, C18.1, J2.1, J4.1, R7.2, R8.2, R10.2, U1.1 (IOVDD), U1.10 (IOVDD), U1.22 (IOVDD), U1.33 (IOVDD), U1.42 (IOVDD), U1.43 (ADC_AVDD), U1.44 (VREG_VIN), U1.48 (USB_VDD), U1.49 (IOVDD), U2.2 (VO), U3.8 (VCC)
/GPIO0: J2.5, U1.2 (GPIO0)
/GPIO1: J2.6, U1.3 (GPIO1)
/GPIO2: J2.7, U1.4 (GPIO2)
/GPIO3: J2.8, U1.5 (GPIO3)
/GPIO4: J2.9, U1.6 (GPIO4)
/GPIO5: J2.10, U1.7 (GPIO5)
/GPIO6: J2.11, U1.8 (GPIO6)
/GPIO7: J2.12, U1.9 (GPIO7)
/GPIO8: J2.13, U1.11 (GPIO8)
/GPIO9: J2.14, U1.12 (GPIO9)
/GPIO10: J2.15, U1.13 (GPIO10)
/GPIO11: J2.16, U1.14 (GPIO11)
/GPIO12: J2.17, U1.15 (GPIO12)
/GPIO13: J2.18, U1.16 (GPIO13)
/GPIO14: R9.2, U1.17 (GPIO14)
/GPIO16: J4.18, U1.27 (GPIO16)
/GPIO17: J4.17, U1.28 (GPIO17)
/GPIO18: J4.16, U1.29 (GPIO18)
/GPIO19: J4.15, U1.30 (GPIO19)
/GPIO20: J4.14, U1.31 (GPIO20)
/GPIO21: J4.13, U1.32 (GPIO21)
/GPIO22: J4.12, U1.34 (GPIO22)
/GPIO23: J4.11, U1.35 (GPIO23)
/GPIO24: J4.10, U1.36 (GPIO24)
/GPIO25: J4.9, U1.37 (GPIO25)
/GPIO26/ADC0: J4.8, U1.38 (GPIO26/ADC0)
/GPIO27/ADC1: J4.7, U1.39 (GPIO27/ADC1)
/GPIO28/ADC2: J4.6, U1.40 (GPIO28/ADC2)
/GPIO29/ADC3: J4.5, U1.41 (GPIO29/ADC3)
/QSPI_SCLK: U1.52 (QSPI_SCLK), U3.6 (CLK)
/QSPI_SD0: U1.53 (QSPI_SD0), U3.5 (DI(IO0))
/QSPI_SD1: U1.55 (QSPI_SD1), U3.2 (DO(IO1))
/QSPI_SD2: U1.54 (QSPI_SD2), U3.3 (IO2)
/QSPI_SD3: U1.51 (QSPI_SD3), U3.7 (IO3)
/QSPI_SS: R6.2, R7.1, U1.56 (QSPI_CSN), U3.1 (~CS)
/SWCLK: J3.3, U1.24 (SWCLK)
/SWD: J3.1, U1.25 (SWD)
/USB_D+: J1.A6 (D+), J1.B6 (D+), R5.2
/USB_D-: J1.A7 (D-), J1.B7 (D-), R4.2
/~RESET: R10.1, SW2.2, U1.26 (RUN)
GND: C1.2, C2.2, C3.2, C4.2, C5.2, C6.2, C7.2, C8.2, C9.2, C10.2, C11.2, C12.2, C13.2, C15.2, C16.2, C17.2, C18.2, D3.1 (K), D6.1 (K), J1.A1 (GND), J1.A12 (GND), J1.B1 (GND), J1.B12 (GND), J1.S1 (SHIELD), J2.4, J2.19, J3.2, J4.4, J4.19, R2.1, R3.1, SW1.1, SW2.1, U1.19 (TESTEN), U1.57 (GND), U2.1 (GND), U3.4 (GND), Y1.2, Y1.4
unnamed: C3.1, U1.20 (XIN), Y1.1
unnamed: C4.1, R1.1, Y1.3
unnamed: D3.2 (A), R8.1
unnamed: D6.2 (A), R9.1
unnamed: J1.A5 (CC1), R3.2
unnamed: J1.B5 (CC2), R2.2
unnamed: R1.2, U1.21 (XOUT)
unnamed: R4.1, U1.46 (USB_DM)
unnamed: R5.1, U1.47 (USB_DP)
unnamed: R6.1, SW1.2
VBUS: D4.2 (A), J1.A4 (VBUS), J1.A9 (VBUS), J1.B4 (VBUS), J1.B9 (VBUS), J2.3, J4.3
VHI: C5.1, C6.1, D4.1 (K), D5.1 (K), U2.3 (VI)
VIN: D5.2 (A), J2.2, J4.2

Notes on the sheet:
BOOT
RESET

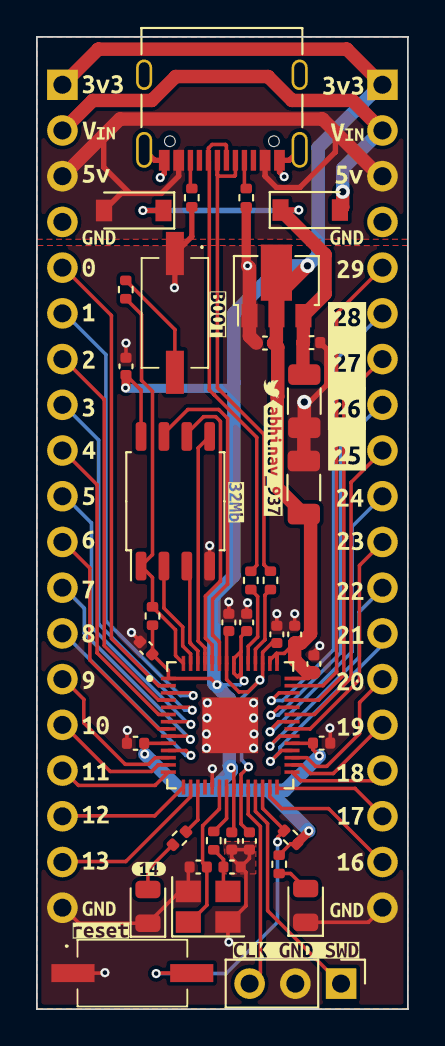
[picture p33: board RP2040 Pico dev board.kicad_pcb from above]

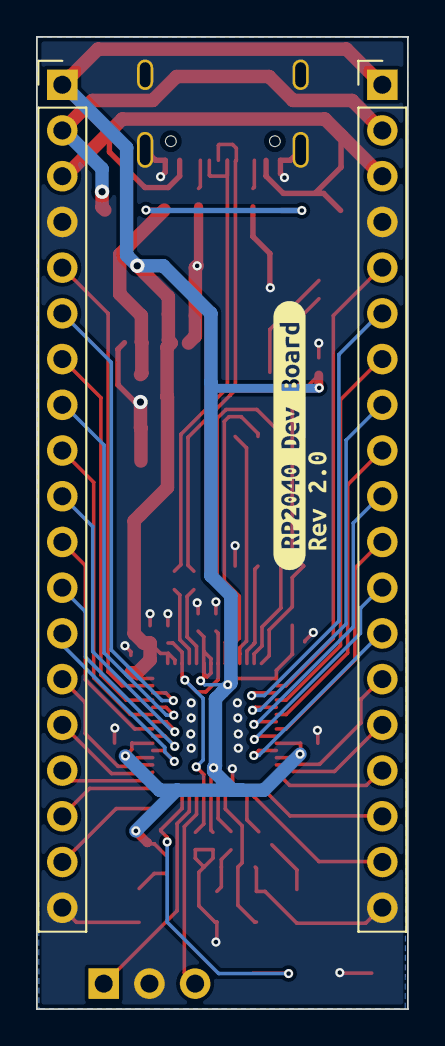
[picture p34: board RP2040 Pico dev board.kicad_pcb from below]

Board: 4 copper layers, 20.6 x 54.0 mm, 90 parts (4 on the bottom side), 56 nets.

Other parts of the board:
G: LOGO; Twitter-logo
kibuzzard-630E1CDD: G***; kibuzzard-630E1CDD
kibuzzard-630E1CF2: G***; kibuzzard-630E1CF2
kibuzzard-630E1CFE: G***; kibuzzard-630E1CFE
kibuzzard-630E1D4B: G***; kibuzzard-630E1D4B
kibuzzard-630E1D5E: G***; kibuzzard-630E1D5E
kibuzzard-630E1D7D: G***; kibuzzard-630E1D7D
kibuzzard-630E1D11: G***; kibuzzard-630E1D11
kibuzzard-630E1D29: G***; kibuzzard-630E1D29
kibuzzard-630E1D34: G***; kibuzzard-630E1D34
kibuzzard-630E1D55: G***; kibuzzard-630E1D55
kibuzzard-630E1D68: G***; kibuzzard-630E1D68
kibuzzard-630E1D83: G***; kibuzzard-630E1D83
kibuzzard-630E1D93: G***; kibuzzard-630E1D93
kibuzzard-630E1DDD: G***; kibuzzard-630E1DDD
kibuzzard-630E1E9D, kibuzzard-630E1E9D#2: G***; kibuzzard-630E1E9D
kibuzzard-630E1E94, kibuzzard-630E1E94#2: G***; kibuzzard-630E1E94
kibuzzard-630E1EE1, kibuzzard-630E1EE1#2: G***; kibuzzard-630E1EE1
kibuzzard-630E1EF5, kibuzzard-630E1EF5#2: G***; kibuzzard-630E1EF5
kibuzzard-630E1F07, kibuzzard-630E1F07#2, kibuzzard-630E1F07#3, kibuzzard-630E1F07#4: G***; kibuzzard-630E1F07
kibuzzard-630E1F17: G***; kibuzzard-630E1F17
kibuzzard-630E20A5: G***; kibuzzard-630E20A5
kibuzzard-630E20AD: G***; kibuzzard-630E20AD
kibuzzard-630E20BA: G***; kibuzzard-630E20BA
kibuzzard-630E20C1: G***; kibuzzard-630E20C1
kibuzzard-630E20C7: G***; kibuzzard-630E20C7
kibuzzard-630E20CF: G***; kibuzzard-630E20CF
kibuzzard-630E20DA: G***; kibuzzard-630E20DA
kibuzzard-630E20E0: G***; kibuzzard-630E20E0
kibuzzard-630E21C9: G***; kibuzzard-630E21C9
kibuzzard-630E22AA: G***; kibuzzard-630E22AA
kibuzzard-630E24DB: G***; kibuzzard-630E24DB
kibuzzard-630E27BD: G***; kibuzzard-630E27BD
kibuzzard-630E27EE: G***; kibuzzard-630E27EE
kibuzzard-630E209E: G***; kibuzzard-630E209E
kibuzzard-630E217B: G***; kibuzzard-630E217B
kibuzzard-630E260B: G***; kibuzzard-630E260B
kibuzzard-630E262A: G***; kibuzzard-630E262A
kibuzzard-630E263B: G***; kibuzzard-630E263B
kibuzzard-630E264D: G***; kibuzzard-630E264D
kibuzzard-630E2104: G***; kibuzzard-630E2104
kibuzzard-630E2223: G***; kibuzzard-630E2223

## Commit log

2022-09-14 Initial Upload of Rev2
    [RP2040 Pico dev board.kicad_pcb, RP2040 Pico dev board.kicad_sch]
2022-09-15 added LCSC BOM
    [RP2040_LCSC_BOM.csv]
